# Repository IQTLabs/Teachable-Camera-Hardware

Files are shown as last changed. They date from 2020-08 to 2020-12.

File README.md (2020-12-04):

# Teachable Camera Hardware

## Introduction

This repository contains the design files that we used for building a Teachable Camera. The Teachable Camera is built using the [Google Coral Dev Board](https://coral.ai/products/dev-board), commercially available components, and a few 3D printed parts. We experimented with a number of different design configurations to aid in development and allow the system to be tested in a more realistic environment.

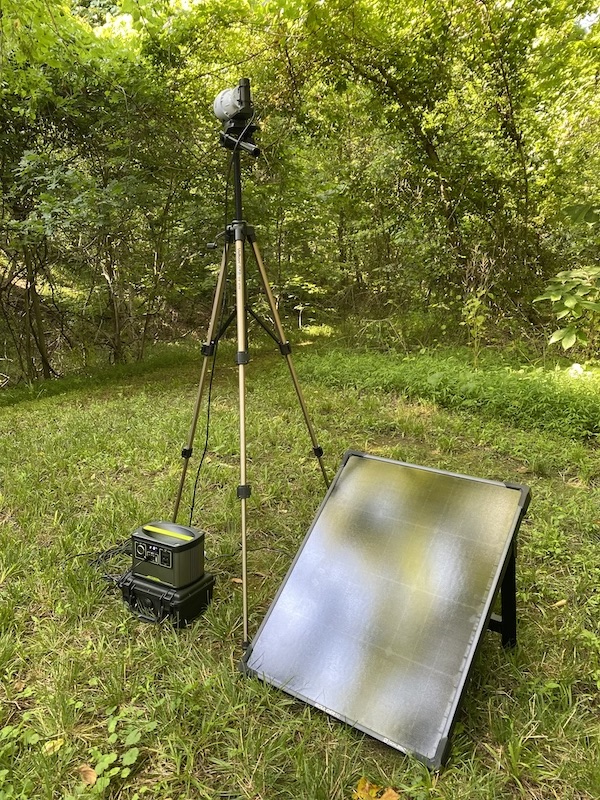
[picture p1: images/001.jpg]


_Teachable Camera in the wild_

## Software

For details about the software that runs on the Coral see the [Teachable Camera Software](https://github.com/IQTLabs/Teachable-Camera) repository

## Design Configurations

There were three designs that we experimented with during the development of the project.

### [Design 1 - Benchtop Testing (Simple 3D Printed Coral Case)](./design-1.md)

The Benchtop Testing hardware is a simple case configuration that houses the Google Coral Development Board and provides a mount which allows you to aim the Coral Camera. The enclosure is 3D printed and provides basic protection for the electronics. This configuration was used to do most of the development and testing of the system.

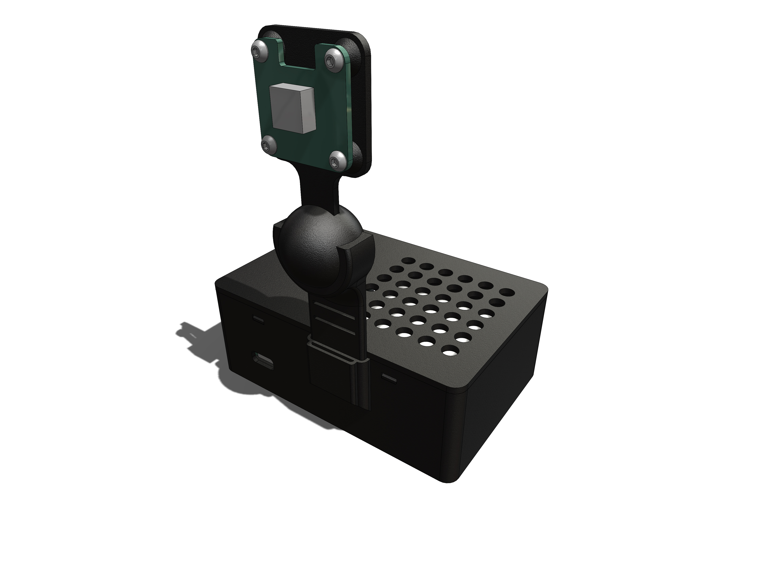
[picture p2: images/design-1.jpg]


See [Design 1 page](./design-1.md) for more details.

### [Design 2 - Light Field Deployment (Coral in Pelican Case with USB Battery)](./design-2.md)

The Light Field Deployment hardware is a simple configuration with a durable case that houses the Google Coral Development Board and large USB battery. This configuration is built upon a 3D printed chassis that holds the Coral, camera, and battery, and is mounted inside a small Pelican case. The configuration allows the system to be deployed in areas without power for short durations and provides more protection when transporting/shipping the system. With a 26800mAh USB battery the system will operate for approximately 10 hours.

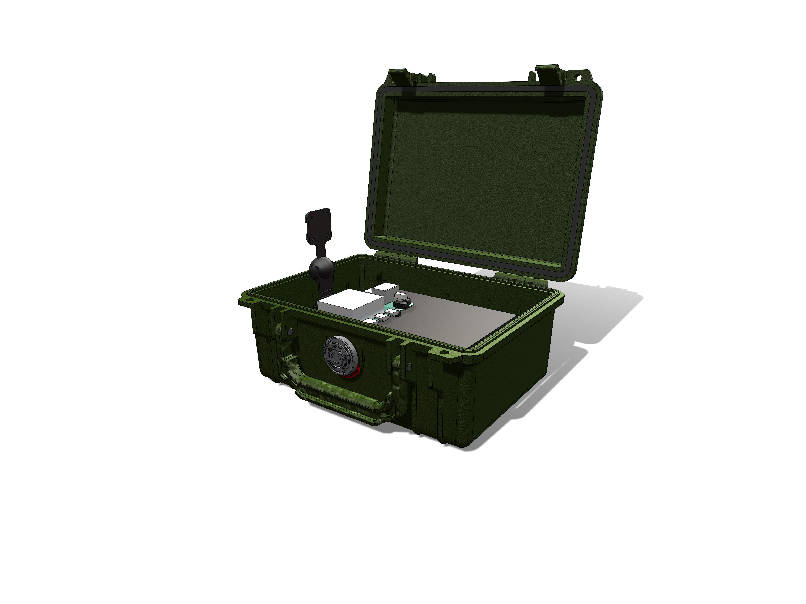
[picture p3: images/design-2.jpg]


See [Design 2 page](./design-2.md) for more details.

### [Design 3 - Extended Run Field Deployment (Coral in Pelican Case, GoalZero Battery, Ubiquity IP Camera](./design-3.md)

The Extended Run Field Deployment hardware is an advanced configuration with a durable case that houses the Google Coral Development Board, a GoalZero battery/solar power system, and a PoE Ubiquity G3 Pro security camera. 

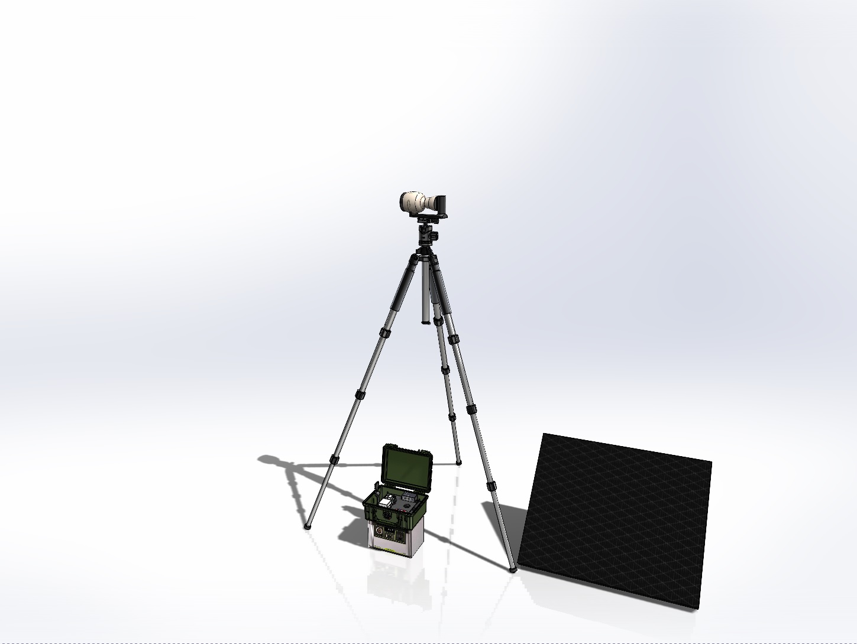
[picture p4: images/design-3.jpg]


See [Design 3 page](./design-3.md) for more details.

## Design Features of Note

### Power/Solar

For the field system (Design 3) power we chose the GoalZero [200X power supply](https://www.goalzero.com/shop/portable-power/goal-zero-yeti-200x/) and the [Boulder 50W](https://www.goalzero.com/shop/solar-panels/boulder-50-solar-panel/) solar panel. The GoalZero power supplies are consumer friendly, the X series is light weight, and there are lots of options for additional battery or solar capacity.

### PoE Power

We needed a way to power the Ubiquity Power over Ethernet (PoE) IP camera using a 5V battery but were unable to located a commerical solution. To solve this we sourced [DC-DC transformer](https://www.amazon.com/Yeeco-Converter-Adjustable-Transformer-Stabilizer/dp/B074J9D278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) to step up the battery voltage from 5V to 48V coupled with a generic [PoE injector](https://www.amazon.com/WS-GPOE-1-WM-Gigabit-Passive-Ethernet-Injector/dp/B00ENNUWO4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) to power the camera. This solution ended up working quite well and could probably be utilized for other projects too. 

### 3D Printing

The 3D printed parts were printed with the Prusa i3 mk3 using PETG filament. PETG is a high temperature material and seems to hold up well even in the summer heat.

## Third Party Files 3D Models

In addition to the models included in this repository, the following files from GRAB CAD were also used in the SolidWorks Assembly for illustration purposes.

- https://grabcad.com/library/google-coral-dev-board-1
- https://grabcad.com/library/coral-camera-1
- https://grabcad.com/library/pelican-case-1150-1
- https://grabcad.com/library/tripod-gtt204-1

## License

<p xmlns:dct="http://purl.org/dc/terms/" xmlns:cc="http://creativecommons.org/ns#" class="license-text">This work by <a rel="cc:attributionURL dct:creator" property="cc:attributionName" href="https://www.iqt.org/labs/">IQT Labs LLC</a> is licensed under <a rel="license" href="https://creativecommons.org/licenses/by/4.0">CC BY 4.0</a></p>

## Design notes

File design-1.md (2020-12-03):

# Design 1

The Benchtop Testing hardware is a simple case configuration that houses the Google Coral Development Board and provides a mount which allows you to aim the Coral Camera. The enclosure is 3D printed and provides basic protection for the electronics. This configuration was used to do most of the development and testing of the system.

## Key Components

- Coral Dev Board
- Coral Camera
- 3D Printed Case

## Design Files 
-   [SolidWorks, STLs](./design-files/design-1/)

## Images and Assembly Diagram

assembly
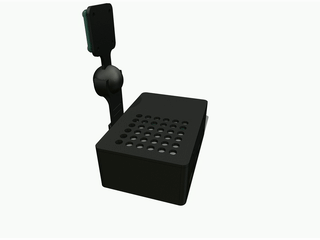
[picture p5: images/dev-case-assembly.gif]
assembly

assembly

## Wiring

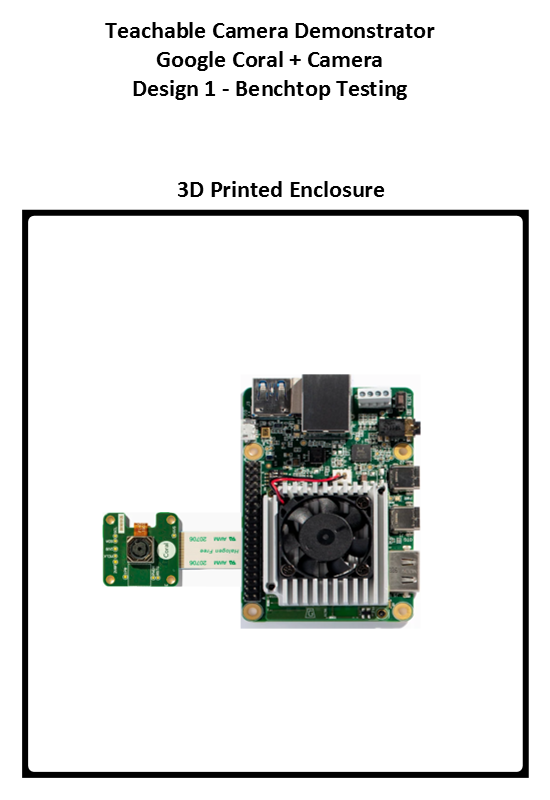
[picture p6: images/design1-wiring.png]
wiring


## BOM

| Item | Quantity | Price | Link | Power Datasheet Spec | Power Actual Measured | Weight | Other |
|---|---|---|---|---|---|---|---|
| Google Coral Dev Board | 1 | $150  | https://coral.ai/products/dev-board | 15W | | < 1lbs | |
| Google Coral Camera | 1 | $20 | https://coral.ai/products/camera/ | | | | |

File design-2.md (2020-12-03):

# Design 2

The Light Field Deployment hardware is a simple configuration with a durable case that houses the Google Coral Development Board and large USB battery. This configuration is built upon a 3D printed chassis that holds the Coral, camera, and battery, and is mounted inside a small Pelican case. The configuration allows the system to be deployed in areas without power for short durations and provides more protection when transporting/shipping the system. With a 26800mAh USB battery the system will operate for approximately 10 hours.

## Key Components
- Coral Dev Board 
- Coral Camera
- Pelican Case
- USB Battery 

## Design Files 
-   [SolidWorks, STLs](./design-files/design-2/)

## Images and Assembly Diagram

assembly
assembly
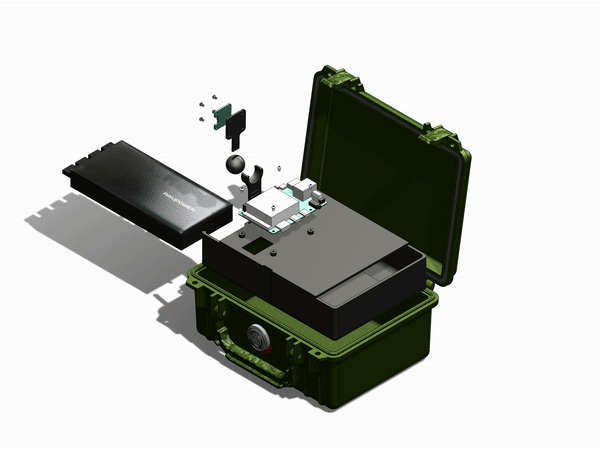
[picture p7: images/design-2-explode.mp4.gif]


## Wiring

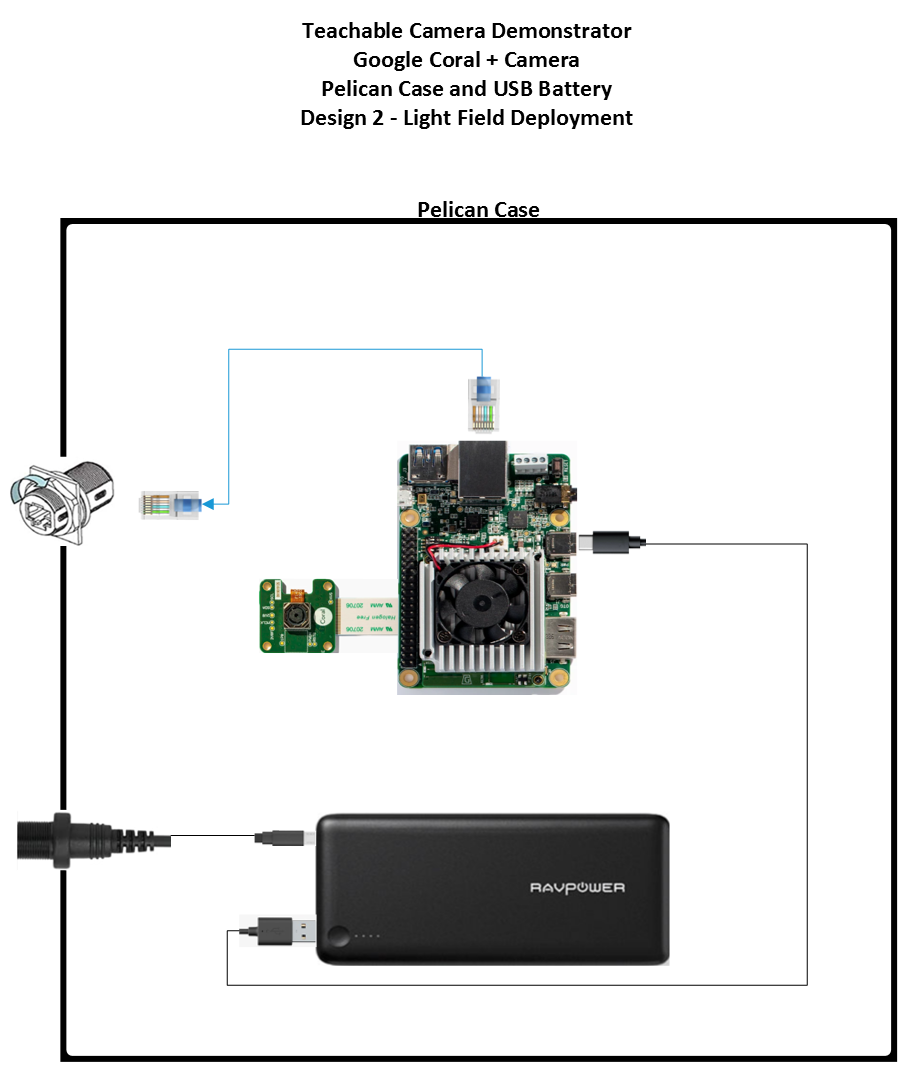
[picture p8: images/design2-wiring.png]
wiring


## Power Consumption and Run Time

Below are cursory power consumption and run time measurements in order to establish the baseline battery life of the system. Note that no significant effort went into minimizing power consumption, and that the system can theoretically run longer than this.

| Device | Power Consumption |
|---|---|
| Coral Dev Board | 6.2W |

| Power Source | Run Time |
|---|---|
| RAV 26800mAh (134Wh) | ~9.5h |

## BOM

| Item | Quantity | Price | Link | Power Datasheet Spec | Power Actual Measured | Weight | Other |
|---|---|---|---|---|---|---|---|
| Google Coral Dev Board | 1 | $150  | https://coral.ai/products/dev-board | 15W | | < 1lbs | |
| Google Coral Camera | 1 | $20 | https://coral.ai/products/camera/ | | | | |
| Misc Connectors | 1 | $25 | https://www.amazon.com/gp/product/B07KSSV8LD/ref=ox_sc_act_title_3?smid=A323VFV6W4CN1S&psc=1     https://www.amazon.com/gp/product/B08169ZB5C/ref=ox_sc_act_title_6?smid=A3MDC9KUHU6B27&psc=1 | N/A | | | |
| Pelican 1150 | 1 | $60 | https://www.bhphotovideo.com/c/product/83166-REG/Pelican_1150_000_110_1150_Case_with_Foam.html | N/A | | ~3lbs  | |
| RAVPower 26800mAh USB Battery Pack | 1 | $45 | https://www.amazon.com/RAVPower-Portable-Charger-26800mAh-External/dp/B012NIQG5E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 | 26800mAh | | ~1lbs  | |

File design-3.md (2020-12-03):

# Design 3

The Extended Run Field Deployment hardware is an advanced configuration with a durable case that houses the Google Coral Development Board, a GoalZero battery/solar power system, and a PoE Ubiquity G3 Pro security camera. 

To power system we chose the GoalZero 200X power station and the Boulder 50W solar panel. The GoalZero power stations are consumer friendly, the X series is light weight, and there are lots of options for additional battery or solar capacity. With this current configuration, the 200X power station provides 24+ hours of run time and with the solar panel (and about 10 hours of sun light) it is capable of running continuously. Note that no significant effort went into minimizing power consumption, and that the system can theoretically run longer than this.

For this configuration we needed a way to power the Ubiquity G3 Pro Power over Ethernet (PoE) IP camera using a 5V USB source but were unaware of a commercial solution to accomplish this. To solve this, we sourced an off-brand DC-DC transformer from Amazon to step up the battery voltage from 5V to 48V.  We then connected it with a generic PoE injector to power the camera. To our surprise this solution ended up working quite well and could probably be utilized for other field PoE projects too.

## Key Components

- Coral Dev Board
- IP Camera (Ubiquity G3 Pro)
- Pelican Case
- GoalZero Battery

## Design Files 
-   [SolidWorks, STLs](./design-files/design-3/)

## Images and Assembly Diagram

assembly
assembly

## Wiring

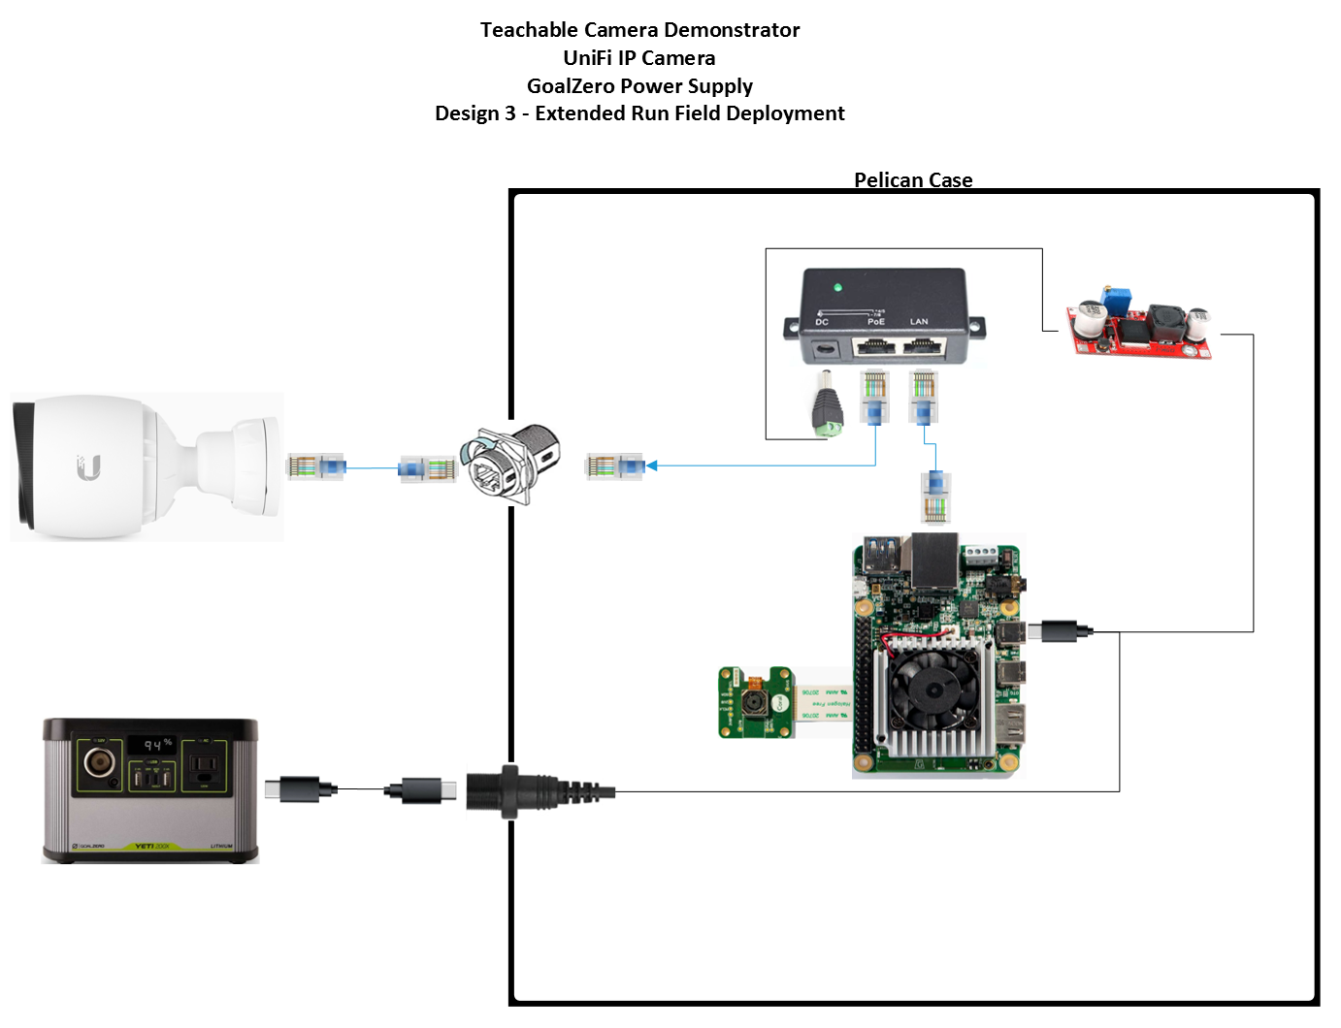
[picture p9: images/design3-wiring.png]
wiring


## Power Consumption and Run Time

Below are cursory power consumption and run time measurements in order to establish the baseline battery life of the system. Note that no significant effort went into minimizing power consumption, and that the system can theoretically run longer than this.

| Device | Power Consumption |
|---|---|
| Coral Dev Board | 6.2W |
| Ubiquity G3 Pro | 4.3/11.1W (day/night IR) |

| Power Source | Run Time |
|---|---|
| GoalZero 200X (~200Wh) | ~25h |
| GoalZero 200X full recharge using 50W solar panel while the system is operating | ~10h |

## BOM

### Key Hardware

| Item | Quantity | Price | Link | Power Datasheet Spec | Power Actual Measured | Weight | Other |
|---|---|---|---|---|---|---|---|
| Google Coral Dev Board | 1 | $150  | https://coral.ai/products/dev-board | 15W | | < 1lbs | |
| UniFi G3 Pro Camera | 1 | $263  | https://www.bhphotovideo.com/c/product/1387763-REG/ubiquiti_networks_uvc_g3_pro_unifi_video_g3_pro_1080p.html | 12.5W | | 1.5lbs | |
| POE Injector | 1 | $15 | https://www.amazon.com/WS-GPOE-1-WM-Gigabit-Passive-Ethernet-Injector/dp/B00ENNUWO4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 | N/A | | < 1lbs | |
| DC-DC Transformer | 1 | $8.59 | https://www.amazon.com/Yeeco-Converter-Adjustable-Transformer-Stabilizer/dp/B074J9D278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 | | | | |
| Ethernet Cable | 2 | $20 | TBD | N/A | | < 1lbs | |
| Misc Connectors | 1 | $25 | https://www.amazon.com/gp/product/B07KSSV8LD/ref=ox_sc_act_title_3?smid=A323VFV6W4CN1S&psc=1     https://www.amazon.com/gp/product/B08169ZB5C/ref=ox_sc_act_title_6?smid=A3MDC9KUHU6B27&psc=1 | N/A | | | |
| Pelican 1150 | 1 | $60 | https://www.bhphotovideo.com/c/product/83166-REG/Pelican_1150_000_110_1150_Case_with_Foam.html | N/A | | ~3lbs  | |
| Heavy Duty Tripod | 1 | $50 | TBD | N/A | | ~10lbs | |
| GoalZero Yeti 200X | 1 | $299  | https://www.goalzero.com/shop/portable-power/goal-zero-yeti-200x/ | 187Wh (Li-ion) | | 5lbs | |
| GoalZero Builder 50W Solar Panel | 1 | $150  | https://www.goalzero.com/shop/solar-panels/boulder-50-solar-panel/ | | | | |

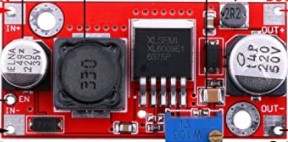
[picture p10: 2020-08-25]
design-files/design-3/solidworks/images/Annotation 2020-08-24 172153.jpg

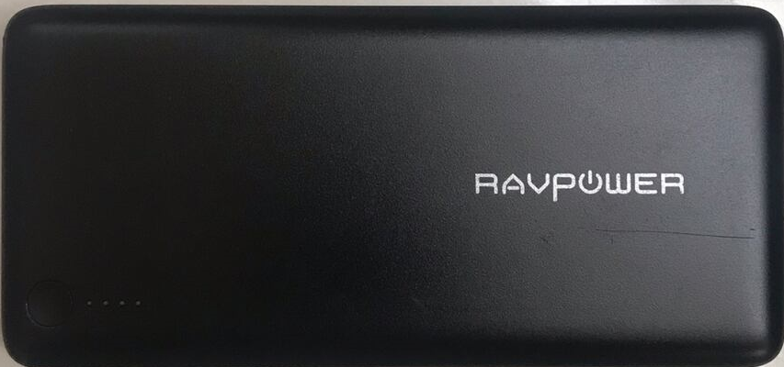
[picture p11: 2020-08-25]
design-files/design-3/solidworks/images/rav.png

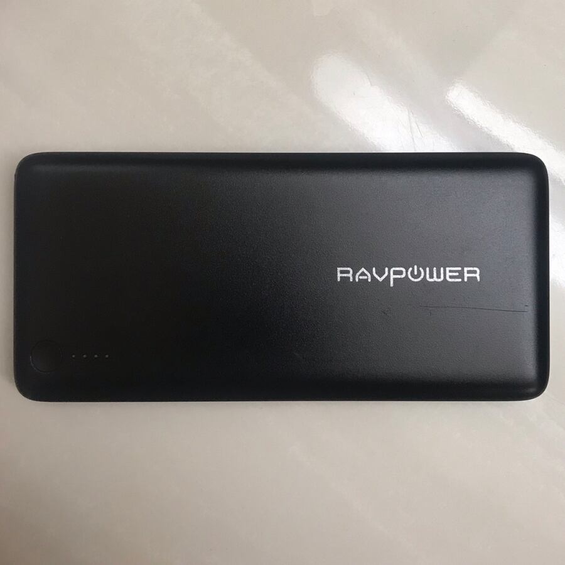
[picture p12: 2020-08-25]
design-files/design-3/solidworks/images/rav.jpg

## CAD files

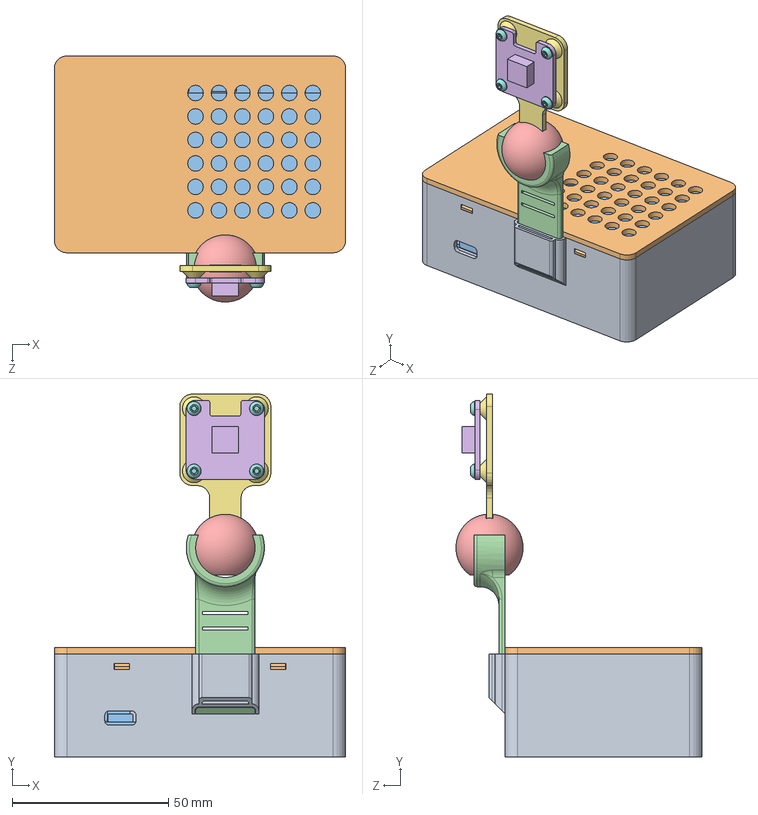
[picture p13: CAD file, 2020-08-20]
design-files/design-1/solidworks/dev case assembly.SLDASM
93.1 x 116.0 x 78.7 mm
case-base
case-lid
Google Coral.step
camera-mount-base
camera-mount-top
Coral Camera.step
camera-mount-top-a
91239A753_CLASS 10.9 STL BUTTON-HEAD SOCKET CAP SCREW x 8

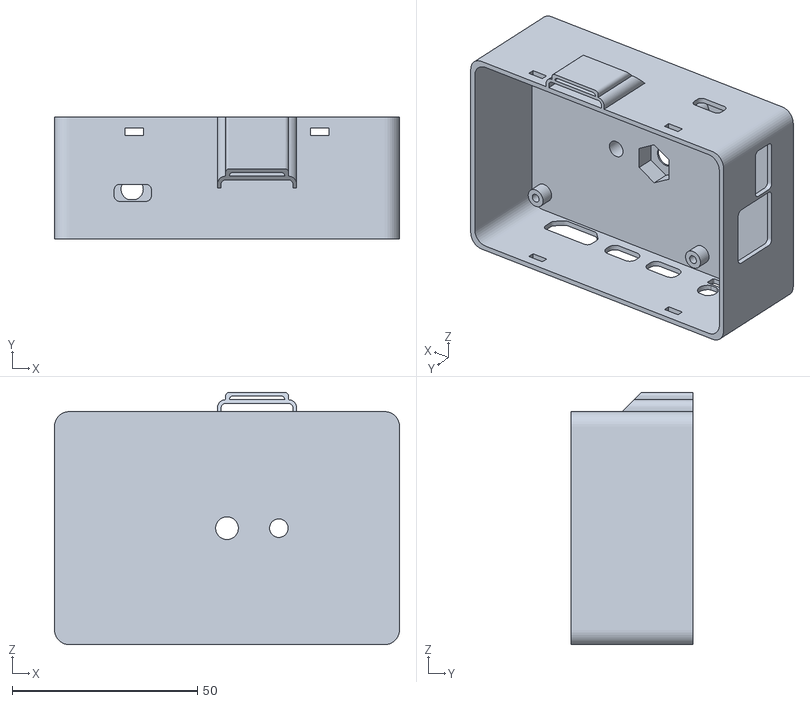
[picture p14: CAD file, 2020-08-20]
design-files/design-1/stl/dev case assembly - case-base.STL
93.1 x 32.9 x 68.1

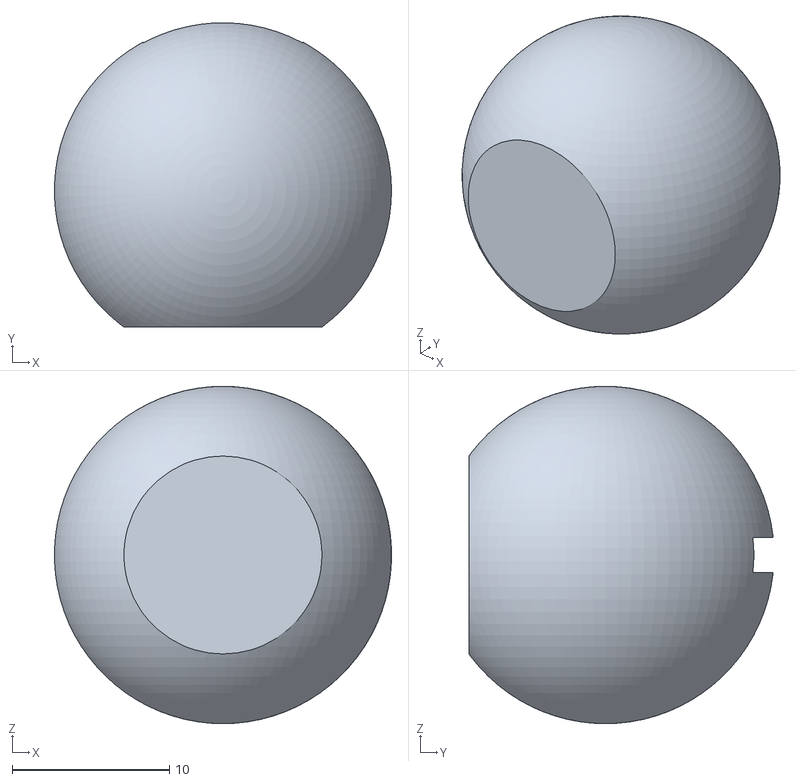
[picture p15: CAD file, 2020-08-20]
design-files/design-1/stl/dev case assembly - camera-mount-balljoint.STL
21.4 x 19.4 x 21.5

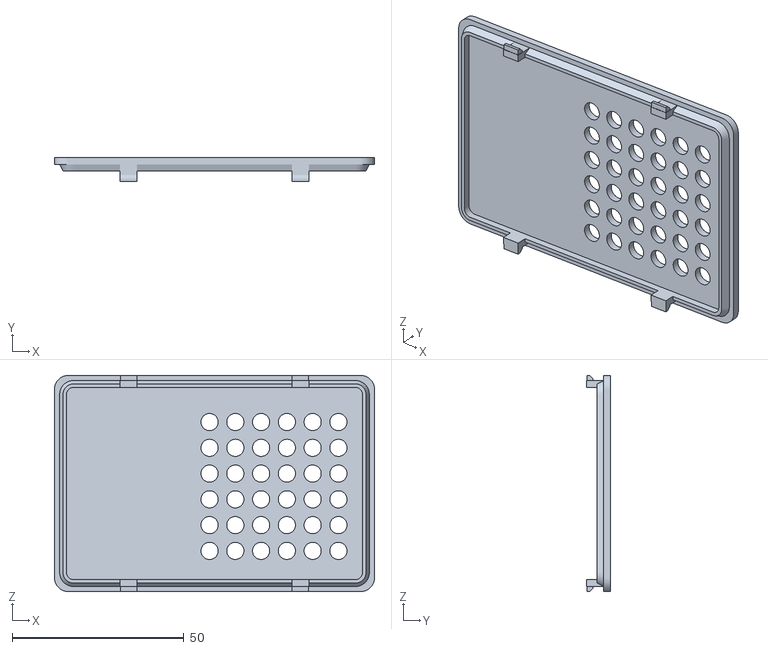
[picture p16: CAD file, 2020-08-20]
design-files/design-1/stl/dev case assembly - case-lid.STL
93.1 x 7.00 x 62.9

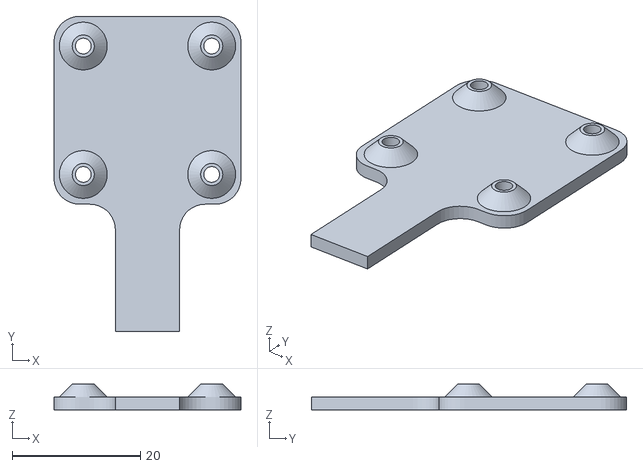
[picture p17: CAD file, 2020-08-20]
design-files/design-1/stl/dev case assembly - camera-mount-top.STL
29.1 x 49.1 x 4.00

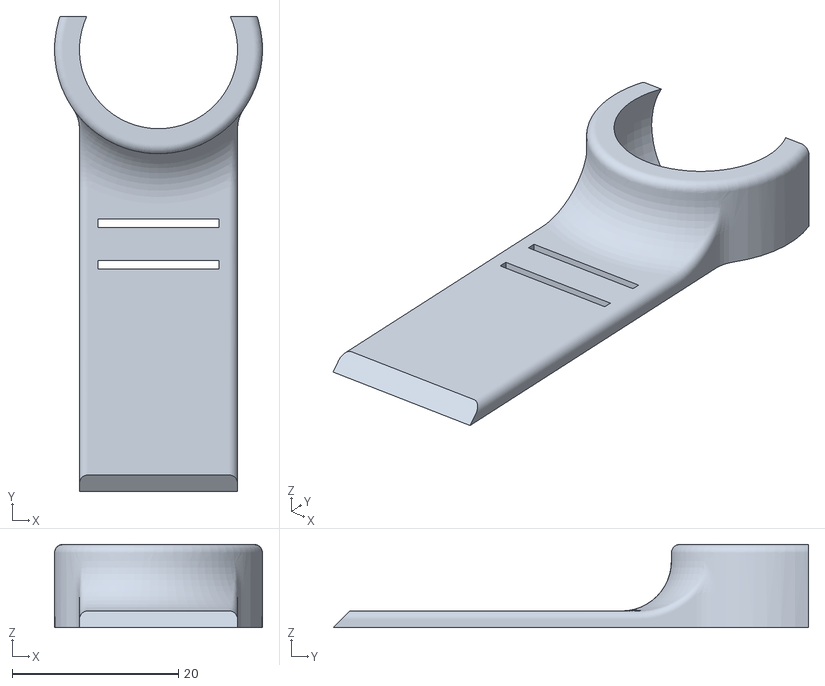
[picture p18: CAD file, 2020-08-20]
design-files/design-1/stl/dev case assembly - camera-mount-base.STL
25.0 x 57.1 x 10.00

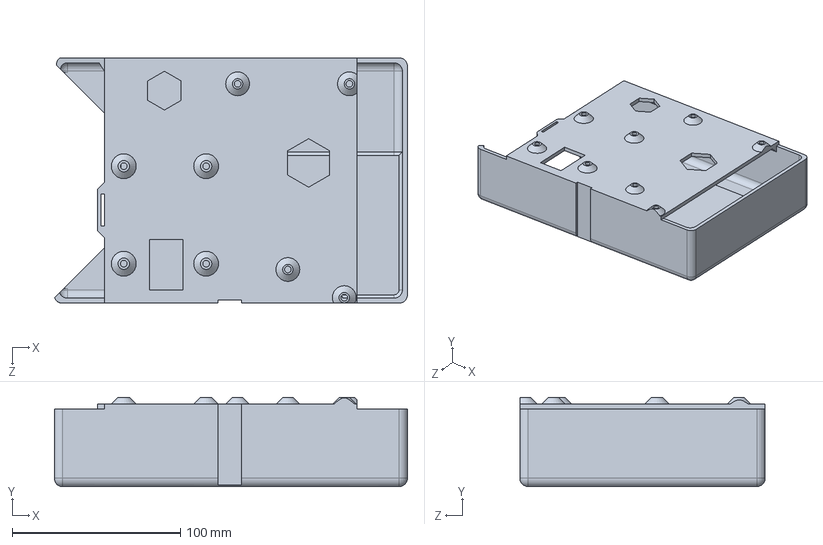
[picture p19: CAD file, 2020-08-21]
design-files/design-2/solidworks/pelican-chassis.SLDPRT
210.0 x 53.0 x 146.0 mm

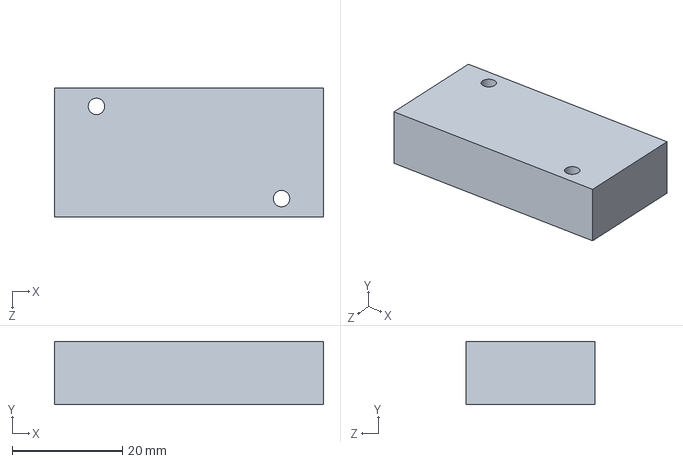
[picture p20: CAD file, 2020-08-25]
design-files/design-3/solidworks/5v-transformer.SLDPRT
48.8 x 11.5 x 23.4 mm

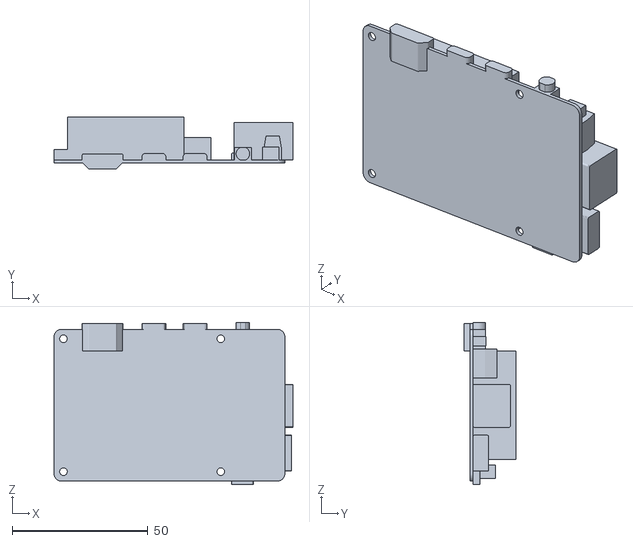
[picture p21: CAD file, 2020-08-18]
design-files/design-3/stl/google-coral-dev-board.STL
88.1 x 19.0 x 59.9

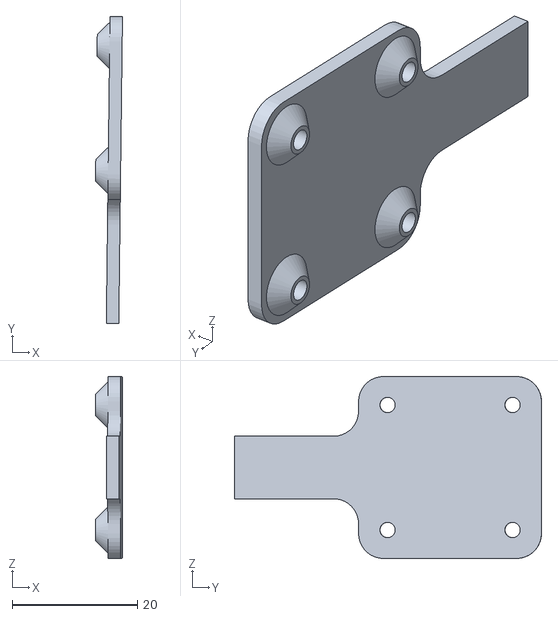
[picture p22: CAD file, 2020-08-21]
design-files/design-2/stl/design-2 - camera-mount-top.STL
4.32 x 49.1 x 29.1

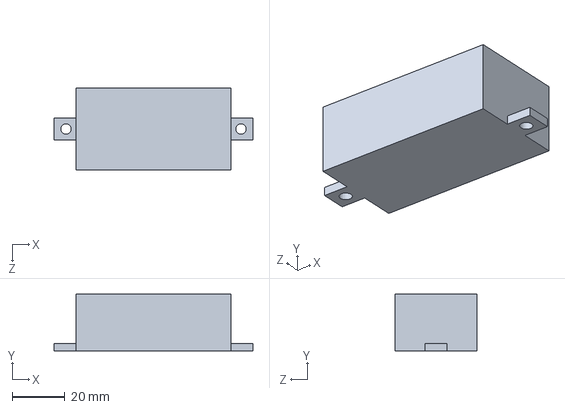
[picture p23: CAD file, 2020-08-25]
design-files/design-3/solidworks/poe-injector.SLDPRT
75.6 x 21.5 x 31.0 mm

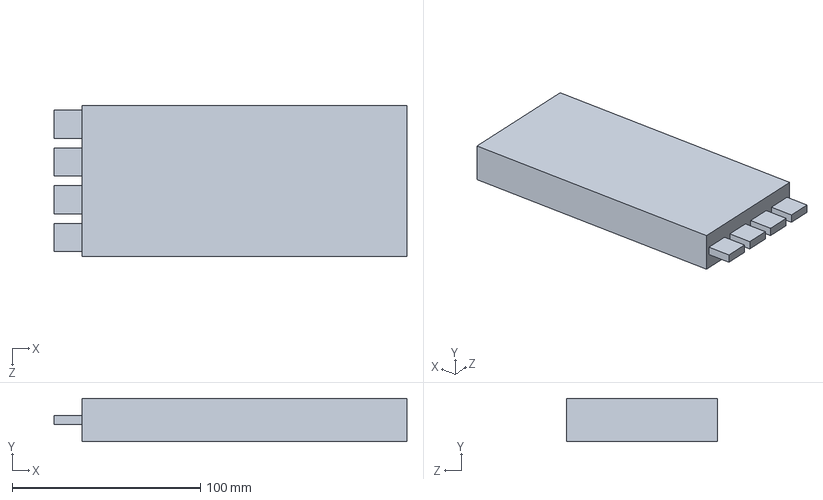
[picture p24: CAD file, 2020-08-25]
design-files/design-3/solidworks/rav-battery-28600.SLDPRT
187.5 x 23.0 x 80.0 mm

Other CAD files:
design-files/design-2/stl/design-2 - camera-mount-base.STL
design-files/design-1/solidworks/camera-mount-top.SLDPRT
design-files/design-2/solidworks/camera-mount-balljoint.SLDPRT
design-files/design-1/solidworks/camera-mount-base.SLDPRT
design-files/design-2/solidworks/camera-mount-top.SLDPRT
design-files/design-2/stl/design-2 - camera-mount-balljoint.STL
design-files/design-1/solidworks/camera-mount-top-a.SLDPRT
design-files/design-1/solidworks/case-base.SLDPRT
design-files/design-1/solidworks/case-lid.SLDPRT
design-files/design-2/solidworks/camera-mount-base.SLDPRT
design-files/design-2/stl/design-2 - pelican-chassis.STL
design-files/design-3/solidworks/camera-mount-balljoint.SLDPRT
design-files/design-3/solidworks/camera-mount-base.SLDPRT
design-files/design-3/solidworks/camera-mount-top.SLDPRT
design-files/design-3/solidworks/goal-zero-boulder-50.SLDPRT
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

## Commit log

2020-08-17 rearrange design files
    [eyeqt-5v-transformer.SLDPRT, eyeqt-goal-zero-boulder-50.SLDPRT, eyeqt-pelican-chassis.SLDPRT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]
2020-08-20 rearrage design files
    [5v-transformer.STL, eyeqt-5v-transformer.SLDPRT, eyeqt-goal-zero-boulder-50.SLDPRT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]
2020-08-20 add dev case stls
    [dev case assembly - camera-mount-base-1.STL, dev case assembly - camera-mount-top-1.STL, dev case assembly - camera-mount-top-a-1.STL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]
2020-08-20 adds dev case assembly animations
2020-08-20 update design 1 files
    [camera-mount-base.SLDPRT, camera-mount-top-a.SLDPRT, camera-mount-top.SLDPRT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]
2020-08-21 design 2 updates
    [camera-mount-balljoint.SLDPRT, camera-mount-base.SLDPRT, camera-mount-top.SLDPRT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]
2020-08-25 rearrange files
    [5v-transformer.SLDPRT, 5v-transformer.STL, camera-mount-balljoint.SLDPRT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]
2020-12-01 Add power consumption details to design pages
2020-12-03 Remove optional BOM items
2020-12-03 update wiring images
